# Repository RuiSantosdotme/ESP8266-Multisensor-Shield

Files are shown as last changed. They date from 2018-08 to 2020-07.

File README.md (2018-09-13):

# ESP8266 Multisensor Shield

In this project you’ll discover how to design and create a Multisensor Shield for the ESP8266 Wemos D1 Mini board. The shield has temperature sensor (DS18B20), a PIR motion sensor, an LDR, and a terminal to connect a relay module. We'll start by preparing all the hardware and then program it.

Watch the video tutorial "Build a Multisensor Shield for ESP8266 - Part 1": https://youtu.be/nKFsNM5Q00k

Watch the video tutorial "Programming Multisensor Shield for ESP8266 - Part 2": https://youtu.be/hxRqLIfabqw

For the complete step-by-step instructions, visit: https://randomnerdtutorials.com/esp8266-multisensor-shield/

How to browse the GitHub repository:
- [ESP8266 web server code (for Arduino IDE)](https://github.com/RuiSantosdotme/ESP8266-Multisensor-Shield/blob/master/Code/ESP8266_Multisensor_Shield/ESP8266_Multisensor_Shield.ino)
- [ESP8266 with Node-RED](https://github.com/RuiSantosdotme/ESP8266-Multisensor-Shield/tree/master/Code/NodeRED_ESP8266_Multisensor_Shield)
- [Schematic diagram](https://github.com/RuiSantosdotme/ESP8266-Multisensor-Shield/tree/master/Images)
- [Gerber files](https://github.com/RuiSantosdotme/ESP8266-Multisensor-Shield/raw/master/KiCad_PCB_ESP8266_Multisensor_Shield/GERBERS/WemosD1MiniShield.zip)
- [KiCad project to edit the PCB](https://github.com/RuiSantosdotme/ESP8266-Multisensor-Shield/tree/master/KiCad_PCB_ESP8266_Multisensor_Shield)
- [3D Enclosure (STL files and SketchUp Project)](https://github.com/RuiSantosdotme/ESP8266-Multisensor-Shield/tree/master/3D_Enclosure)
- [Click here to download all the files](https://github.com/RuiSantosdotme/ESP8266-Multisensor-Shield/archive/master.zip)

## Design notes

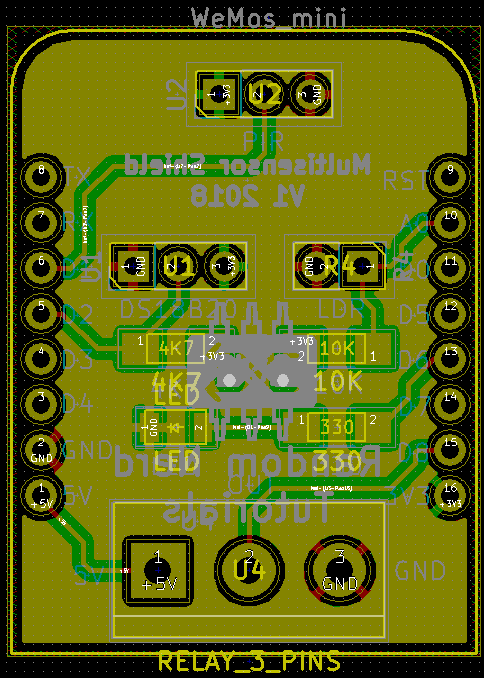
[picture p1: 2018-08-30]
Images/KiCad-PCB-top-view.png

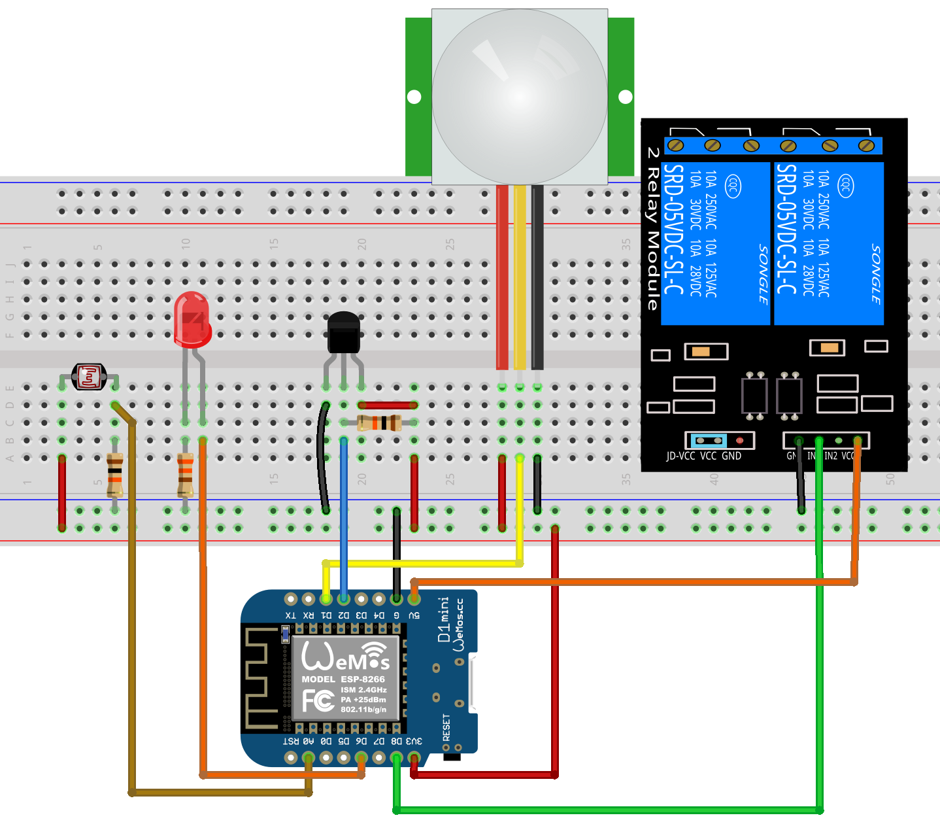
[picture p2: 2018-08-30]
Images/ESP8266-shield-breadboard.png

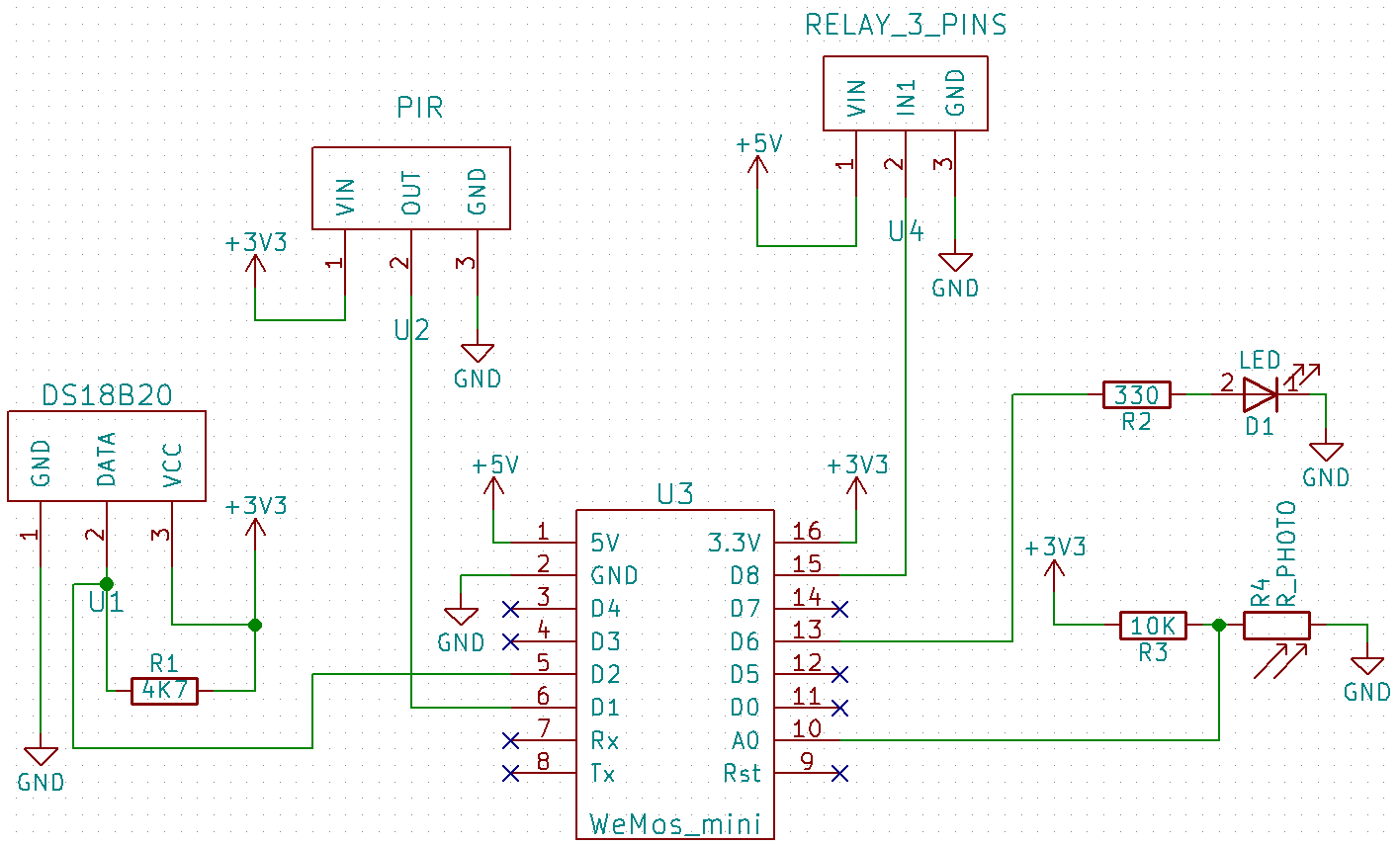
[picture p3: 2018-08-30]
Images/KiCad-circuit.png

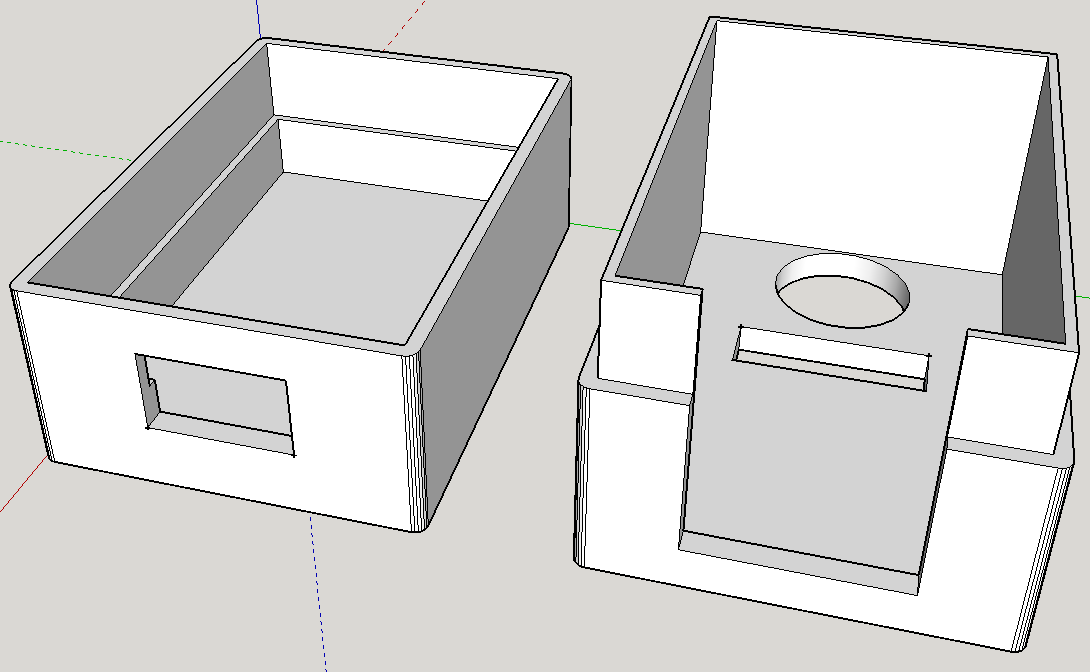
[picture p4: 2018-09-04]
3D_Enclosure/Enclosure_Image.png

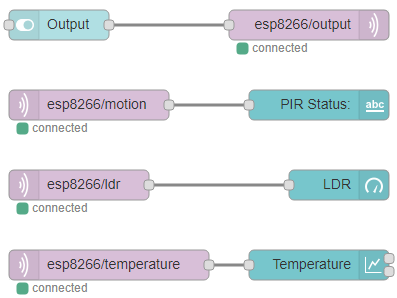
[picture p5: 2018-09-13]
Code/NodeRED_ESP8266_Multisensor_Shield/Node-RED-flow-example.PNG

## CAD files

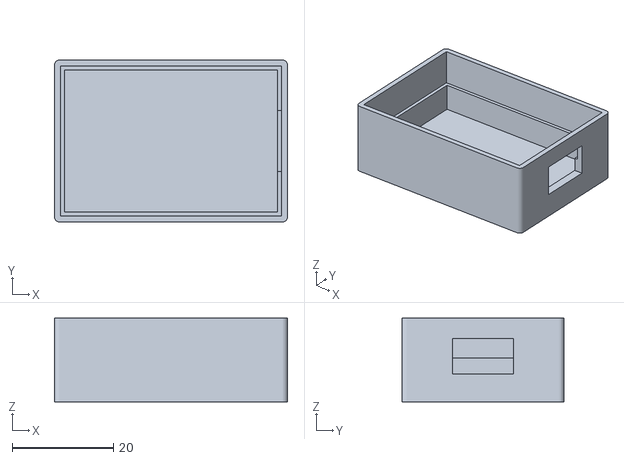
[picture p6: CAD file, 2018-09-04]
3D_Enclosure/enclosure_bottom.stl
46.0 x 32.0 x 16.5

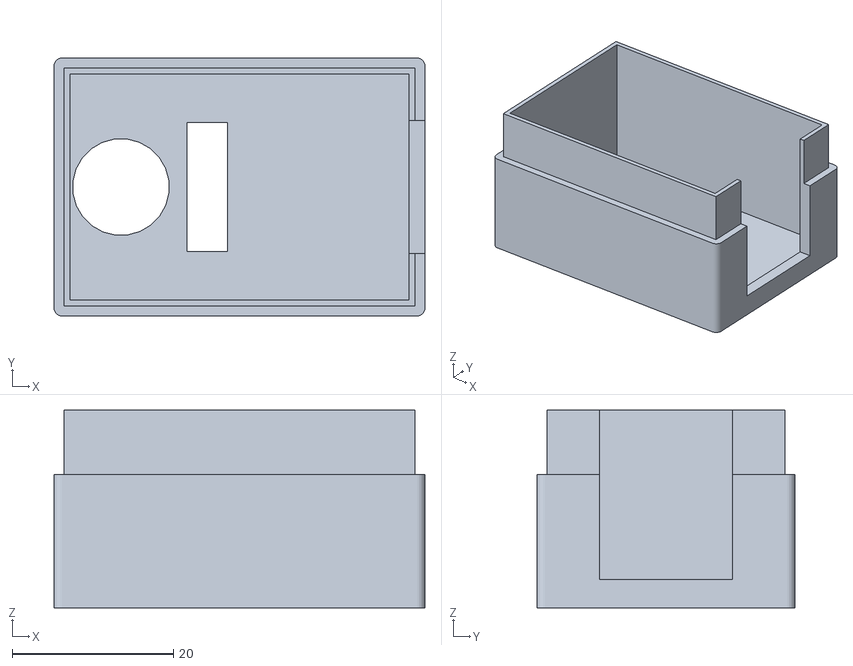
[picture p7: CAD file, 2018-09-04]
3D_Enclosure/enclosure_lid.stl
46.0 x 32.0 x 24.5

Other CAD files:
3D_Enclosure/enclosure_project.skp

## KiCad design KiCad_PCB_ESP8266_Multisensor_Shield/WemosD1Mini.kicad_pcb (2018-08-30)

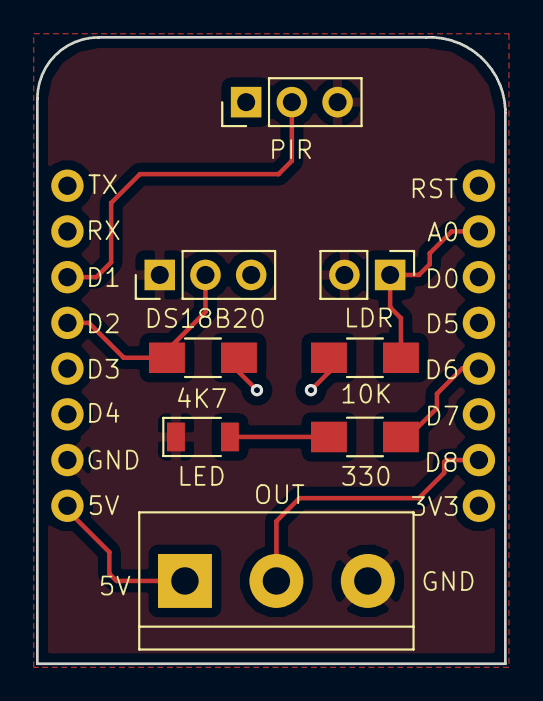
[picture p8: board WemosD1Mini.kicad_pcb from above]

Board: 2 copper layers, 26.0 x 34.8 mm, 9 parts (0 on the bottom side), 9 nets.

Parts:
4K7: 4K7; R_1206_HandSoldering
10K: 10K; R_1206_HandSoldering
330: 330; R_1206_HandSoldering
LED: LED; D_1206
R4: LDR; Pin_Header_Straight_1x02_Pitch2.54mm
U1: DS18B20; Pin_Header_Straight_1x03_Pitch2.54mm
U2: PIR; Pin_Header_Straight_1x03_Pitch2.54mm
U3: WeMos_mini; Wemos_D1_Mini_Shield_No_SilkS
U4: RELAY_3_PINS; TerminalBlock_bornier-3_P5.08mm

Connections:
+3V3: 4K7.2, 10K.2, U1.3, U2.1, U3.16
+5V: U3.1, U4.1
GND: LED.1, R4.2, U1.1, U2.3, U3.2, U4.3
unnamed: 330.1, LED.2
unnamed: 4K7.1, U1.2, U3.5
unnamed: 330.2, U3.13
unnamed: 10K.1, R4.1, U3.10
unnamed: U2.2, U3.6
unnamed: U3.15, U4.2

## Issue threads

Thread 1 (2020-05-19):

Modify for non-surface mount components

anthonyjclarke, 2020-05-19:
Has anyone modified this PCB to support non-surface mount (?) components.  Newbie here and would like to use "traditional" / Through Hole components.

Thanks

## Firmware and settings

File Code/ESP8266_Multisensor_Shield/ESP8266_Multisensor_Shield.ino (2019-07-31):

/*********
  Rui Santos
  Complete project details at https://randomnerdtutorials.com  
*********/

// Load libraries
#include <ESP8266WiFi.h>
#include <EEPROM.h>
#include <OneWire.h>
#include <DallasTemperature.h>

// Replace with your network credentials
const char* ssid     = "REPLACE_WITH_YOUR_SSID";
const char* password = "REPLACE_WITH_YOUR_PASSWORD";

// Auxiliary variables for temperature
static char celsiusTemp[7];
static char fahrenheitTemp[7];
String temperatureString = "";      // Variable to hold the temperature reading

// EEPROM size
// Address 0: Last output state (0 = off or 1 = on)
// Address 1: Selected mode (0 = Manual, 1 = Auto PIR,
// 2 = Auto LDR, or 3 = Auto PIR and LDR)
// Address 2: Timer (time 0 to 255 seconds)
// Address 3: LDR threshold value (luminosity in percentage 0 to 100%)
#define EEPROM_SIZE 4

// Set GPIOs for: output variable, status LED, PIR Motion Sensor, and LDR
const int output = 15;
const int statusLed = 12;
const int motionSensor = 5;
const int ldr = A0;
// Store the current output state
String outputState = "off";

// GPIO where the DS18B20 is connected to
const int oneWireBus = 4;          
// Setup a oneWire instance to communicate with any OneWire devices
OneWire oneWire(oneWireBus);
// Pass our oneWire reference to Dallas Temperature sensor 
DallasTemperature sensors(&oneWire);

// Timers - Auxiliary variables
unsigned long now = millis();
unsigned long lastMeasure = 0;
boolean startTimer = false;
unsigned long currentTime = millis();
unsigned long previousTime = 0; 
const long timeoutTime = 2000;

// Auxiliary variables to store selected mode and settings 
int selectedMode = 0;
int timer = 0;
int ldrThreshold = 0;
int armMotion = 0;
int armLdr = 0;
String modes[4] = { "Manual", "Auto PIR", "Auto LDR", "Auto PIR and LDR" };

// Decode HTTP GET value
String valueString = "0";
int pos1 = 0;
int pos2 = 0;
// Variable to store the HTTP request
String header;
// Set web server port number to 80
WiFiServer server(80);

void setup() {
  // Start the DS18B20 sensor
  sensors.begin();

  // Serial port for debugging purposes
  Serial.begin(115200);

  // PIR Motion Sensor mode, then set interrupt function and RISING mode
  pinMode(motionSensor, INPUT_PULLUP);
  attachInterrupt(digitalPinToInterrupt(motionSensor), detectsMovement, RISING);
  
  Serial.println("start...");
  EEPROM.begin(EEPROM_SIZE);
  
  // Uncomment the next lines to test the values stored in the flash memory
  /*Serial.println(" bytes read from Flash . Values are:");
  for(int i = 0; i < EEPROM_SIZE; i++) {
    Serial.print(byte(EEPROM.read(i))); 
    Serial.print(" ");
  }*/
  
  // Initialize the output variable and the LED as OUTPUTs
  pinMode(output, OUTPUT);
  pinMode(statusLed, OUTPUT);
  digitalWrite(output, HIGH);
  digitalWrite(statusLed, LOW);
  // Read from flash memory on start and store the values in auxiliary variables
  // Set output to last state (saved in the flash memory)
  if(!EEPROM.read(0)) {
    outputState = "off";
    digitalWrite(output, HIGH);
  }
  else {
    outputState = "on";
    digitalWrite(output, LOW);
  }
  selectedMode = EEPROM.read(1);
  timer = EEPROM.read(2);
  ldrThreshold = EEPROM.read(3);
  configureMode();
  
  // Connect to Wi-Fi network with SSID and password
  Serial.print("Connecting to ");
  Serial.println(ssid);
  WiFi.begin(ssid, password);
  while (WiFi.status() != WL_CONNECTED) {
    delay(500);
    Serial.print(".");
  }
  // Print local IP address and start web server
  Serial.println("");
  Serial.println("WiFi connected.");
  Serial.println("IP address: ");
  Serial.println(WiFi.localIP());
  server.begin();
}

void loop() {
  WiFiClient client = server.available();   // Listen for incoming clients
  if (client) {                             // If a new client connects,
    currentTime = millis();
    previousTime = currentTime;
    Serial.println("New Client.");          // print a message out in the serial port
    String currentLine = "";                // make a String to hold incoming data from the client
    while (client.connected() && currentTime - previousTime <= timeoutTime) {            // loop while the client's connected
      currentTime = millis();
      if (client.available()) {             // if there's bytes to read from the client,
        char c = client.read();             // read a byte, then
        Serial.write(c);                    // print it out the serial monitor
        header += c;
        if (c == '\n') {                    // if the byte is a newline character
          // if the current line is blank, you got two newline characters in a row.
          // that's the end of the client HTTP request, so send a response:
          if (currentLine.length() == 0) {
            // HTTP headers always start with a response code (e.g. HTTP/1.1 200 OK)
            // and a content-type so the client knows what's coming, then a blank line:
            client.println("HTTP/1.1 200 OK");
            client.println("Content-type:text/html");
            client.println("Connection: close");
            client.println();                     
            // Display the HTML web page
            client.println("<!DOCTYPE html><html>");
            client.println("<head><meta name=\"viewport\" content=\"width=device-width, initial-scale=1\">");
            client.println("<link rel=\"icon\" href=\"data:,\">");
            // CSS to style the on/off buttons 
            // Feel free to change the background-color and font-size attributes to fit your preferences
            client.println("<style>html { font-family: Helvetica; display: inline-block; margin: 0px auto; text-align: center;}");
            client.println(".button { background-color: #4CAF50; border: none; color: white; padding: 16px 40px;");
            client.println("text-decoration: none; font-size: 30px; margin: 2px; cursor: pointer;}");
            client.println(".button2 {background-color: #555555;}</style></head>");
            
            // Request example: GET /?mode=0& HTTP/1.1 - sets mode to Manual (0)
            if(header.indexOf("GET /?mode=") >= 0) {
              pos1 = header.indexOf('=');
              pos2 = header.indexOf('&');
              valueString = header.substring(pos1+1, pos2);
              selectedMode = valueString.toInt();
              EEPROM.write(1, selectedMode);
              EEPROM.commit();
              configureMode();
            }
            // Change the output state - turn GPIOs on and off
            else if(header.indexOf("GET /?state=on") >= 0) {
              outputOn();
            } 
            else if(header.indexOf("GET /?state=off") >= 0) {
              outputOff();
            }
            // Set timer value
            else if(header.indexOf("GET /?timer=") >= 0) {
              pos1 = header.indexOf('=');
              pos2 = header.indexOf('&');
              valueString = header.substring(pos1+1, pos2);
              timer = valueString.toInt();
              EEPROM.write(2, timer);
              EEPROM.commit();
              Serial.println(valueString);
            }
            // Set LDR Threshold value
            else if(header.indexOf("GET /?ldrthreshold=") >= 0) {
              pos1 = header.indexOf('=');
              pos2 = header.indexOf('&');
              valueString = header.substring(pos1+1, pos2);
              ldrThreshold = valueString.toInt();
              EEPROM.write(3, ldrThreshold);
              EEPROM.commit();
              Serial.println(valueString);
            }
            
            // Web Page Heading
            client.println("<body><h1>ESP8266 Web Server</h1>");
            // Drop down menu to select mode
            client.println("<p><strong>Mode selected:</strong> " + modes[selectedMode] + "</p>");
            client.println("<select id=\"mySelect\" onchange=\"setMode(this.value)\">");
            client.println("<option>Change mode");
            client.println("<option value=\"0\">Manual");
            client.println("<option value=\"1\">Auto PIR");
            client.println("<option value=\"2\">Auto LDR");
            client.println("<option value=\"3\">Auto PIR and LDR</select>");
          
            // Display current state, and ON/OFF buttons for output 
            client.println("<p>GPIO - State " + outputState + "</p>");
            // If the output is off, it displays the ON button       
            if(selectedMode == 0) {
              if(outputState == "off") {
                client.println("<p><button class=\"button\" onclick=\"outputOn()\">ON</button></p>");
              } 
              else {
                client.println("<p><button class=\"button button2\" onclick=\"outputOff()\">OFF</button></p>");
              }
            }
            else if(selectedMode == 1) {
              client.println("<p>Timer (0 and 255 in seconds): <input type=\"number\" name=\"txt\" value=\"" + 
                              String(EEPROM.read(2)) + "\" onchange=\"setTimer(this.value)\" min=\"0\" max=\"255\"></p>");
            }
            else if(selectedMode == 2) {
              client.println("<p>LDR Threshold (0 and 100%): <input type=\"number\" name=\"txt\" value=\"" + 
                              String(EEPROM.read(3)) + "\" onchange=\"setThreshold(this.value)\" min=\"0\" max=\"100\"></p>");
            }
            else if(selectedMode == 3) {
              client.println("<p>Timer (0 and 255 in seconds): <input type=\"number\" name=\"txt\" value=\"" + 
                               String(EEPROM.read(2)) + "\" onchange=\"setTimer(this.value)\" min=\"0\" max=\"255\"></p>");
              client.println("<p>LDR Threshold (0 and 100%): <input type=\"number\" name=\"txt\" value=\"" + 
                               String(EEPROM.read(3)) + "\" onchange=\"setThreshold(this.value)\" min=\"0\" max=\"100\"></p>");            
            }
            // Get and display DHT sensor readings
            if(header.indexOf("GET /?sensor") >= 0) {
              sensors.requestTemperatures(); 
              temperatureString = " " + String(sensors.getTempCByIndex(0)) + "C  " +  
                        String(sensors.getTempFByIndex(0)) + "F";   
             
              client.println("<p>");
              client.println(temperatureString);
              client.println("</p>");
              client.println("<p><a href=\"/\"><button>Remove Sensor Readings</button></a></p>");
            }
            else {
              client.println("<p><a href=\"?sensor\"><button>View Sensor Readings</button></a></p>");
            }
            client.println("<script> function setMode(value) { var xhr = new XMLHttpRequest();"); 
            client.println("xhr.open('GET', \"/?mode=\" + value + \"&\", true);"); 
            client.println("xhr.send(); location.reload(true); } ");
            client.println("function setTimer(value) { var xhr = new XMLHttpRequest();");
            client.println("xhr.open('GET', \"/?timer=\" + value + \"&\", true);"); 
            client.println("xhr.send(); location.reload(true); } ");
            client.println("function setThreshold(value) { var xhr = new XMLHttpRequest();");
            client.println("xhr.open('GET', \"/?ldrthreshold=\" + value + \"&\", true);"); 
            client.println("xhr.send(); location.reload(true); } ");
            client.println("function outputOn() { var xhr = new XMLHttpRequest();");
            client.println("xhr.open('GET', \"/?state=on\", true);"); 
            client.println("xhr.send(); location.reload(true); } ");
            client.println("function outputOff() { var xhr = new XMLHttpRequest();");
            client.println("xhr.open('GET', \"/?state=off\", true);"); 
            client.println("xhr.send(); location.reload(true); } ");
            client.println("function updateSensorReadings() { var xhr = new XMLHttpRequest();");
            client.println("xhr.open('GET', \"/?sensor\", true);"); 
            client.println("xhr.send(); location.reload(true); }</script></body></html>");
            // The HTTP response ends with another blank line
            client.println();
            // Break out of the while loop
            break;
          } else { // if you got a newline, then clear currentLine
            currentLine = "";
          }
        } else if (c != '\r') {  // if you got anything else but a carriage return character,
          currentLine += c;      // add it to the end of the currentLine
        }
      }
    }
    // Clear the header variable
    header = "";
    // Close the connection
    client.stop();
    Serial.println("Client disconnected.");
  }
  
  // Starts a timer to turn on/off the output according to the time value or LDR reading
  now = millis();
  
  // Mode selected (1): Auto PIR
  if(startTimer && armMotion && !armLdr) {
    if(outputState == "off") {
      outputOn();
    }
    else if((now - lastMeasure > (timer * 1000))) {
      outputOff();
      startTimer = false;     
    }
  }  
  
  // Mode selected (2): Auto LDR
  // Read current LDR value and turn the output accordingly
  if(armLdr && !armMotion) {
    int ldrValue = map(analogRead(ldr), 0, 1023, 0, 100); 
    Serial.println(ldrValue);
    if(ldrValue < ldrThreshold && outputState == "on") {
      outputOff();
    }
    else if(ldrValue > ldrThreshold && outputState == "off") {
      outputOn();
    }
    delay(100);
  }
  
  // Mode selected (3): Auto PIR and LDR
  if(startTimer && armMotion && armLdr) {
    int ldrValue = map(analogRead(ldr), 0, 1023, 0, 100);
    Serial.println(ldrValue);
    if(ldrValue < ldrThreshold) {
      outputOff();
      startTimer = false;
      Serial.println("a");
    }
    else if(ldrValue > ldrThreshold && outputState == "off") {
      outputOn();
      Serial.println("b");
    }
    else if(now - lastMeasure > (timer * 1000)) {
      outputOff();
      startTimer = false;
      Serial.println("c");
    }
  }
}

// Checks if motion was detected and the sensors are armed. Then, starts a timer.
ICACHE_RAM_ATTR void detectsMovement() {
  if(armMotion || (armMotion && armLdr)) {
    Serial.println("MOTION DETECTED!!!");
    startTimer = true;
    lastMeasure = millis();
  }  
}
void configureMode() {
  // Mode: Manual
  if(selectedMode == 0) {
    armMotion = 0;
    armLdr = 0;
    // Status LED: off
    digitalWrite(statusLed, LOW);
  }
  // Mode: Auto PIR
  else if(selectedMode == 1) {
    outputOff();
    armMotion = 1;
    armLdr = 0;
    // Status LED: on
    digitalWrite(statusLed, HIGH);
  }
  // Mode: Auto LDR
  else if(selectedMode == 2) {
    armMotion = 0;
    armLdr = 1;
    // Status LED: on    
    digitalWrite(statusLed, HIGH);
  }
  // Mode: Auto PIR and LDR
  else if(selectedMode == 3) {
    outputOff();
    armMotion = 1;
    armLdr = 1;
    // Status LED: on
    digitalWrite(statusLed, HIGH);
  }
}

// Change output pin to on or off
void outputOn() {
  Serial.println("GPIO on");
  outputState = "on";
  digitalWrite(output, LOW);
  EEPROM.write(0, 1);
  EEPROM.commit();
}
void outputOff() { 
  Serial.println("GPIO off");
  outputState = "off";
  digitalWrite(output, HIGH);
  EEPROM.write(0, 0);
  EEPROM.commit();
}

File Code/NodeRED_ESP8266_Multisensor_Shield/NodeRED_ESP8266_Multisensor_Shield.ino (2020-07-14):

/*********
  Rui Santos
  Complete project details at https://randomnerdtutorials.com  
*********/

// Load libraries
#include <ESP8266WiFi.h>
#include <PubSubClient.h>
#include <OneWire.h>
#include <DallasTemperature.h>

// Replace with your network credentials
const char* ssid     = "REPLACE_WITH_YOUR_SSID";
const char* password = "REPLACE_WITH_YOUR_PASSWORD";

// Change the variable to your Raspberry Pi IP address, so it connects to your MQTT broker
const char* mqtt_server = "REPLACE_WITH_YOUR_MQTT_BROKER";
// MQTT Broker IP example
//const char* mqtt_server = "192.168.1.144";

// Initializes the espClient. You should change the espClient name if you have multiple ESPs running in your home automation system
WiFiClient espClient;
PubSubClient client(espClient);

// Variable to hold the temperature reading
String temperatureString = "";

// Set GPIOs for: output variable, status LED, PIR Motion Sensor, and LDR
const int output = 15;
const int statusLed = 12;
const int motionSensor = 5;
const int ldr = A0;
// Store the current output state
String outputState = "off";

// GPIO where the DS18B20 is connected to
const int oneWireBus = 4;          
// Setup a oneWire instance to communicate with any OneWire devices
OneWire oneWire(oneWireBus);
// Pass our oneWire reference to Dallas Temperature sensor 
DallasTemperature sensors(&oneWire);

// Timers - Auxiliary variables
unsigned long now = millis();
unsigned long lastMeasure = 0;
boolean startTimer = false;
unsigned long currentTime = millis();
unsigned long previousTime = 0; 

// Don't change the function below. 
// This function connects your ESP8266 to your router
void setup_wifi() {
  delay(10);
  // We start by connecting to a WiFi network
  Serial.println();
  Serial.print("Connecting to ");
  Serial.println(ssid);
  WiFi.begin(ssid, password);
  while (WiFi.status() != WL_CONNECTED) {
    delay(500);
    Serial.print(".");
  }
  Serial.println("");
  Serial.print("WiFi connected - ESP IP address: ");
  Serial.println(WiFi.localIP());
}

// This functions is executed when some device publishes a message to a topic that your ESP8266 is subscribed to
// Change the function below to add logic to your program, so when a device publishes a message to a topic that 
// your ESP8266 is subscribed you can actually do something
void callback(String topic, byte* message, unsigned int length) {
  Serial.print("Message arrived on topic: ");
  Serial.print(topic);
  Serial.print(". Message: ");
  String messageTemp;
  
  for (int i = 0; i < length; i++) {
    Serial.print((char)message[i]);
    messageTemp += (char)message[i];
  }
  Serial.println();

  // Feel free to add more if statements to control more GPIOs with MQTT
  // If a message is received on the topic esp8266/output, you check if the message is either on or off. 
  // Turns the output according to the message received
  if(topic=="esp8266/output"){
    Serial.print("Changing output to ");
    if(messageTemp == "on"){
      digitalWrite(output, LOW);
      Serial.print("on");
    }
    else if(messageTemp == "off"){
      digitalWrite(output, HIGH);
      Serial.print("off");
    }
  }
  Serial.println();
}

// This functions reconnects your ESP8266 to your MQTT broker
// Change the function below if you want to subscribe to more topics with your ESP8266 
void reconnect() {
  // Loop until we're reconnected
  while (!client.connected()) {
    Serial.print("Attempting MQTT connection...");
    // Create a random client ID
    String clientId = "ESP8266Client-";
    clientId += String(random(0xffff), HEX);
    // Attempt to connect
    if (client.connect(clientId.c_str())) {
      Serial.println("connected");  
      // Subscribe or resubscribe to a topic
      // You can subscribe to more topics (to control more outputs)
      client.subscribe("esp8266/output");  
    } else {
      Serial.print("failed, rc=");
      Serial.print(client.state());
      Serial.println(" try again in 5 seconds");
      // Wait 5 seconds before retrying
      delay(5000);
    }
  }
}

// Checks if motion was detected and the sensors are armed. Then, starts a timer.
ICACHE_RAM_ATTR void detectsMovement() {
  Serial.println("MOTION DETECTED!");
  client.publish("esp8266/motion", "MOTION DETECTED!");
  previousTime = millis();
  startTimer = true;
}

void setup() {
  // Start the DS18B20 sensor
  sensors.begin();

  // Serial port for debugging purposes
  Serial.begin(115200);

  // PIR Motion Sensor mode, then set interrupt function and RISING mode
  pinMode(motionSensor, INPUT_PULLUP);
  attachInterrupt(digitalPinToInterrupt(motionSensor), detectsMovement, RISING);
  
  // Initialize the output variable and the LED as OUTPUTs
  pinMode(output, OUTPUT);
  pinMode(statusLed, OUTPUT);
  digitalWrite(output, HIGH);
  digitalWrite(statusLed, LOW);
  
  setup_wifi();
  client.setServer(mqtt_server, 1883);
  client.setCallback(callback);
}

void loop() {
  if (!client.connected()) {
    reconnect();
  }
  client.loop();
  
  // Timer variable with current time
  now = millis();

  // Publishes new temperature and LDR readings every 30 seconds
  if (now - lastMeasure > 30000) {
    lastMeasure = now;
    sensors.requestTemperatures(); 
    // Temperature in Celsius degrees
    temperatureString = String(sensors.getTempCByIndex(0));
    // Uncomment the next line for temperature in Fahrenheit degrees
    //temperatureString = String(sensors.getTempFByIndex(0));
    // Publishes Temperature values
    client.publish("esp8266/temperature", temperatureString.c_str());
    Serial.println("Temperature published");
    
    // Publishes LDR values
    client.publish("esp8266/ldr", String(analogRead(ldr)).c_str());
    Serial.println("LDR values published");    
  }
  // After 10 seconds have passed since motion was detected, publishes a "No motion" message
  if ((now - previousTime > 10000) && startTimer) { 
    client.publish("esp8266/motion", "No motion");
    Serial.println("Motion stopped");
    startTimer = false;
  }
}

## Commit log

2018-08-30 KiCad project, Images, and Arduino code
    [WemosD1Mini-B.Cu.gbr, WemosD1Mini-B.Mask.gbr, WemosD1Mini-B.SilkS.gbr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]
2018-09-04 3D Enclosure, Code updated, and Readme
    [enclosure_bottom.stl, enclosure_lid.stl, enclosure_project.skp]
2018-09-13 ESP8266 Multisensor Shield Node-RED
    [NodeRED_Config_Example.txt]
2018-09-13 Node-RED flow example screenshot
